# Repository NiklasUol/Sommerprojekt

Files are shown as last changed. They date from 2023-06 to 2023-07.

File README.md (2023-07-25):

# Sommerprojekt
This code is for your university summer project

WHAT THE PROJECT DOES
  Our project is a clock that helps you to wake up. It does that by only being able to turned off by pushing a button that is far away from the clock. 

WHY THE PROJECT IS USEFUL
  With this placement of clock and off-button, we intend to force your users to walk, which makes you more wack and decreases the chance that you lay yourself back into your bed.

HOW USERS CAN GET STARTED WITH THE PROJECT
  Since we tinkered a bit of hardware to getter to build our own clock, it mid be a bit difficult to start right a way. 
  clock and the off-switch consists of a Wemos D1 Mini each, for control and for Wi-Fi capability, an 8-Ohm speaker, button: VS15 and an HT16K33 Display from Adafruit.

WHO MAINTAINS AND CONTRIBUTES TO THE PROJECT & WHERE CAN I GET HELP ?
  This project was created and is maintained by Renke Beckmann, Minh Duc Pham, Niklas Schmidt and Jan von Garrel. 
  If you have any questions on this, feel free to write us a mail at "plantstone98@gmail.com".

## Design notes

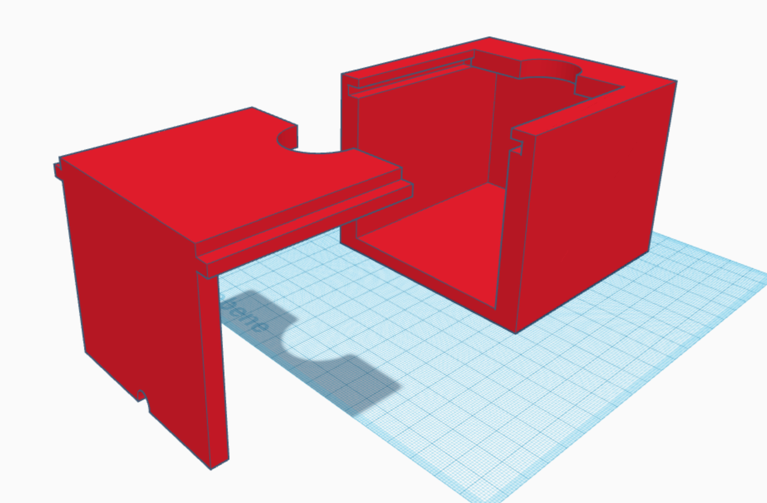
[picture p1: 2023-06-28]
3D Modelle/Knopf/Knopf Gehäuse (offen).png

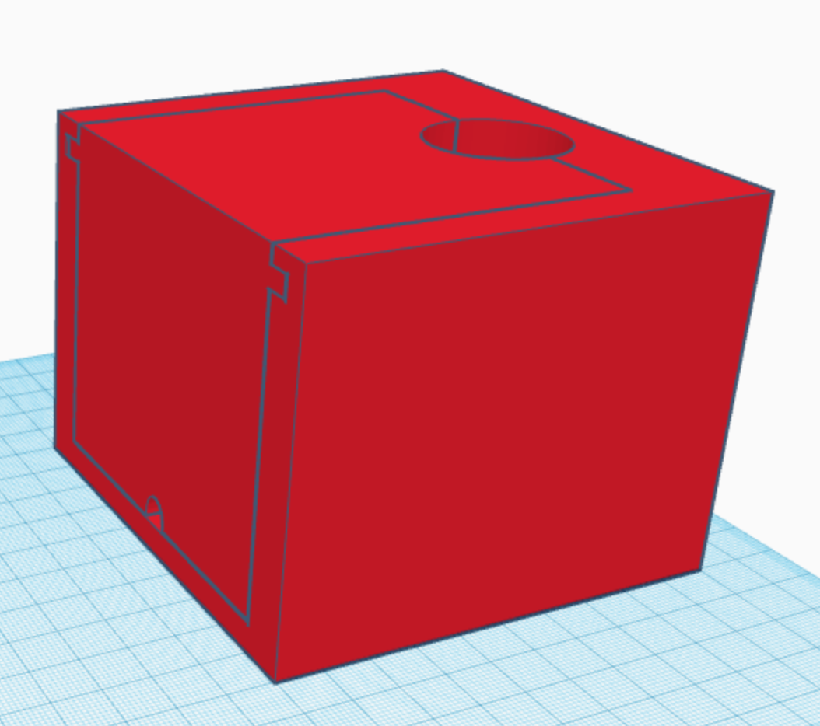
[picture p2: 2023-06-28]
3D Modelle/Knopf/Knopf Gehäuse (geschlossen).png

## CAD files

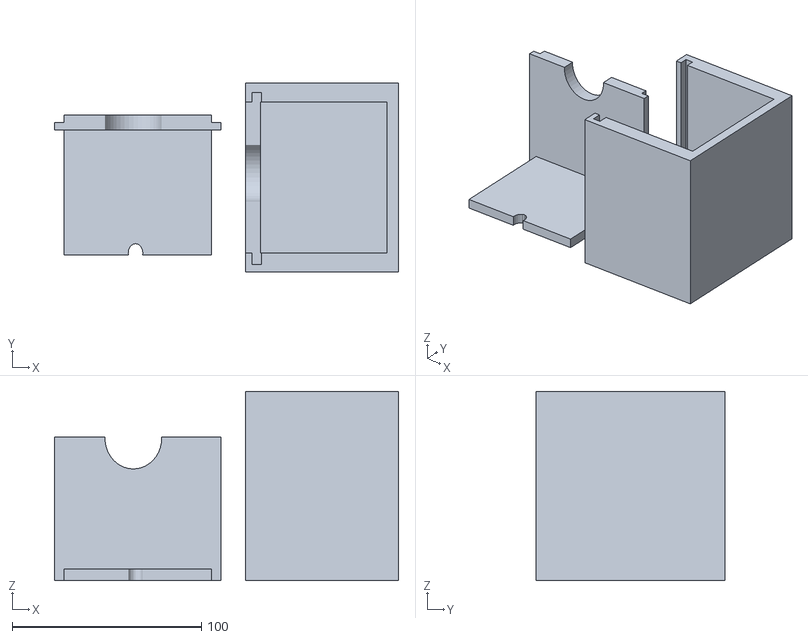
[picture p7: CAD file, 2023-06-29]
3D Modelle/Knopf/Gehäuse Knopf Teil 1 und 2.stl
182.0 x 100.0 x 100.0

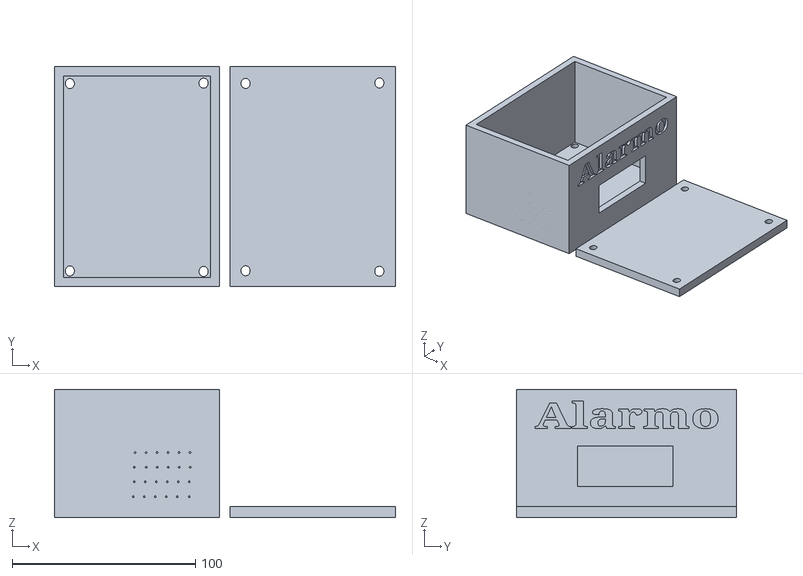
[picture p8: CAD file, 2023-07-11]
3D Modelle/Wecker/Gehäuse Wecker.stl
186.1 x 120.1 x 70.0

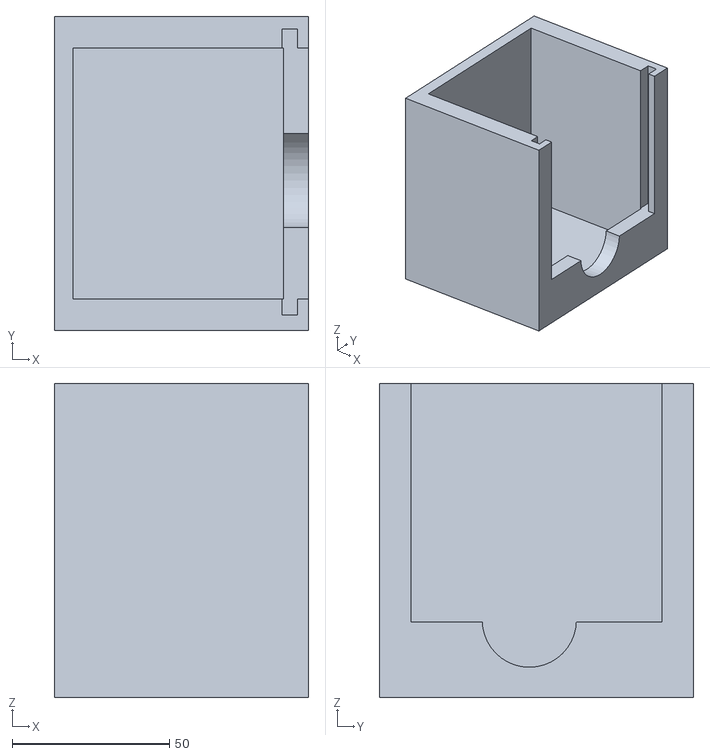
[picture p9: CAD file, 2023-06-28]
3D Modelle/Knopf/Knopf Gehäuse Teil 1.stl
81.0 x 100.0 x 100.0

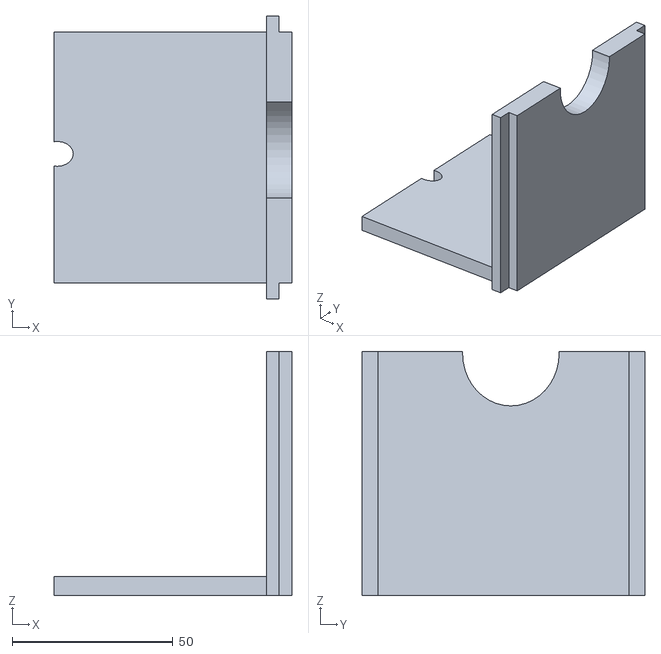
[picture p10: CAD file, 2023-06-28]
3D Modelle/Knopf/Knopf Gehäuse Teil 2.stl
74.0 x 88.0 x 76.0

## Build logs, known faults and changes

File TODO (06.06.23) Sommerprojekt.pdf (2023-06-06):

### TODO

Wecker (Wecker.ino):

- getCurrentTime() : int
- Gibt die aktuelle Uhrzeit zurück. Holt sich diese über WLAN. Methode wird in setup() aufgerufen. Danach wird die Zeit über millis() weiterberechnet.
- updateTime()
- Aktualisiert die Uhrzeit, welche als Attribut gespeichert wird. Dazu kann millis() und die Startuhrzeit, welche in setup() geladen wird, genutzt werden.
- Ruft alarm() auf, wenn die Uhrzeit mit der aktualisierten Weckzeit übereinstimmt.
- alarm()
- Startet den Alarm und setzt ein globales Attribut „alarmAktiv“ auf true. Der Alarm wird so lange abgespielt, bis „alarmAktiv“ false ist. Dazu muss ein Buzzer angesteuert werden.
- onMqttMessage(int messageSize)
- Ist schon vorhanden. Muss so bearbeitet werden, dass auch auf das Topic mit dem Alarm-Stopp-Signal geprüft wird. Wenn ein Signal erhalten wurde, wird das globale Attribut „alarmAktiv“ auf false gesetzt.

Display (Wecker.ino):

- displayTime(int hour, int minute)
- Die aktuelle Zeit wird auf dem Display angezeigt. Dazu wird die Adafruit-Libary genutzt und Inputs und Outputs in setup() gesetzt.

Mobiler-Aus-Knopf (neu zu erstellende Arduino-Projektdatei):

- sendSignal(String signal)
- Es wird ein Signal an den Wecker gesendet. Dazu müssen Broker und Topic mit dem Wecker übereinstimmen.
- Das Signal wird gesendet, wenn der Knopf gedrückt wurde. Diese Bedingung wird in der loop() geprüft. Außerdem muss der digitale Pin des Knopfes definiert- und als Input in setup() gesetzt werden.

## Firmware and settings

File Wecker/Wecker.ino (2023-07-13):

#include <WiFiManager.h>
#include <ArduinoMqttClient.h>

#include <WiFiUdp.h>
#include <NTPClient.h>

//Display
#include <Wire.h>
#include <Adafruit_GFX.h>
#include "Adafruit_LEDBackpack.h"

WiFiManager wifiManager;
WiFiClient client;

//Fuer Zeitabruf
WiFiUDP ntpUDP;
NTPClient timeClient(ntpUDP);

//Mqtt Settings
MqttClient mqttClient(client);
const char broker[] = "broker.hivemq.com";
//const char broker[] = "public.mqtthq.com";

int port = 1883;
const char topicWeckzeit[] = "wecker/weckzeit";
const char topicStopAlarm[] = "wecker/stopAlarm";
const char topicSettings[] = "wecker/settings";

//Wecker-Attribute
int weckminute = 0;
int weckstunde = 0;
bool alarm = false;

bool dimDisplay = false;
bool displayIsDimmed = false;
int dimTime = 22; //22Uhr
int helligkeit = 15;

//Pins (GPIO Nummern entsprechen nicht Anschluessen)
const int buzzer = 14; //D5
const int CLK = D1; //Set the CLK pin connection to the display
const int DIO = D2; //Set the DIO pin connection to the display

Adafruit_7segment display = Adafruit_7segment();

void updateTimeClient();

void setup() {
  Serial.begin(115200);
  display.begin(0x70);
  display.print("LOAd");
  display.blinkRate(3);
  display.setBrightness(helligkeit); //set the diplay to maximum brightness
  display.writeDisplay();
  wifiManager.autoConnect("Wecker");

  mqttSetup();
  mqttSubscribe(topicWeckzeit);
  mqttSubscribe(topicStopAlarm);
  mqttSubscribe(topicSettings);

  timeClient.begin();
  timeClient.setTimeOffset(7200);
  timeClient.setUpdateInterval(86400000);  //Zeit wird alle 24h neu geladen
  updateTimeClient();

  pinMode(buzzer, OUTPUT);
  digitalWrite(buzzer,LOW);

  tone(buzzer, 700, 500);

  display.blinkRate(0);
  display.writeDisplay();
}



void loop() {
  mqttClient.poll();   //Haelt die MQTT Verbindung aufrecht
  updateTimeClient();  //Laedt die Zeit regelmaeßig vom Server
  startAlarm();        //Startet Alarm, wenn die Weckzeit stimmt
  setDisplay(timeClient.getHours(), timeClient.getMinutes()); //Zeitanzeige
 // mqttReconnector();  //Stellt Verbindung wieder her, wenn der Wecker vom Broker getrennt wurde
}



void mqttSetup() {
  Serial.print("Versuche mit folgendem MQTT-Broker zu verbinden: ");
  Serial.println(broker);

  while (!mqttClient.connect(broker, port)) {
    Serial.print("MQTT Verbindung fehlgeschlagen! Error: ");
    Serial.println(mqttClient.connectError());
    tone(buzzer, 100, 500);
    display.print("NOCO");
    display.writeDisplay();
    delay(2000);
  }

  Serial.println("Erfolgreich verbunden!");
  Serial.println();

  mqttClient.onMessage(onMqttMessage);
}

void mqttReconnector(){
  if(!mqttClient.connected()){
    Serial.println("MQTT Verbindung fehlgeschlagen! Versuche Verbindung wiederherzustellen...");
    if(mqttClient.connect(broker, port)){
      Serial.println("MQTT Verbindung wiederhergestellt");
      mqttClient.onMessage(onMqttMessage);
    }
    else{
      Serial.print("Konnte MQTT Verbindung nicht wiederherstellen. Error: ");
      Serial.println(mqttClient.connectError());
      delay(2000);
    }
  }
}

void mqttSubscribe(const char topic[]) {
  mqttClient.subscribe(topic);
  Serial.print("Mit folgendem Mqtt-Topic verbunden: ");
  Serial.println(topic);
}

//Ausgabe der empfangenden Nachricht und Speicherung der Weckzeit
void onMqttMessage(int messageSize) {
  Serial.print("Uhrzeit: ");
  Serial.println(timeClient.getFormattedTime());
  Serial.println("Nachricht mit folgendem Topic erhalten: '");
  String receivedTopic = mqttClient.messageTopic();
  Serial.print(receivedTopic);
  Serial.print("', laenge ");
  Serial.print(messageSize);
  Serial.println(" bytes:");

  // Nachricht lesen und ausgeben
  String nachricht;
  while (mqttClient.available()) {
    nachricht = nachricht + (char)mqttClient.read();
  }
  Serial.println(nachricht);
  Serial.println();

  if (receivedTopic.equals(topicWeckzeit)) {
    Serial.println("Weckzeit " + nachricht + " gespeichert!");
    int deviderIndex = nachricht.indexOf(':');
    weckstunde = nachricht.substring(0, deviderIndex).toInt();
    weckminute = nachricht.substring(deviderIndex + 1).toInt();

    //Sendet Empfangsbestaetigung an Smartphone zurueck
    const char sendTopic[] = "wecker/response";
    sendMqttMessage(sendTopic, "Daten erhalten!");
    
    //Signalton zur Bestätigung
    for(int i = 0; i < 30; i++){
      tone(buzzer, 300 + (20 * i), 100);
    }
    
    //Wecker zeigt empfangende Zeit an
    for(int i = 0; i < 5; i++){
      setDisplay(weckstunde, weckminute);
      delay(1000);
      display.clear();
      display.writeDisplay();
      delay(1000);
    }
  }

  if (receivedTopic.equals(topicStopAlarm)) {
    alarm = false;
    Serial.println("Alarm gestopp!");
  }

  if(receivedTopic.equals(topicSettings)){
    int receivedHelligkeit = nachricht.substring(0).toInt();
    if(receivedHelligkeit == 0){
      helligkeit = 0;
    }
    else{
      helligkeit = receivedHelligkeit * 2 + 1;
    }
    display.setBrightness(helligkeit);
    display.writeDisplay();
    sendMqttMessage("wecker/response", "Settings erhalten");
    tone(buzzer, 700, 500);

    if(nachricht.length() > 1){
      dimTime = nachricht.substring(2, nachricht.length()).toInt();
      dimDisplay = true;
    }
    else {
      dimDisplay = false;
      displayIsDimmed = false;
    }
  }
}

void sendMqttMessage(const char sendTopic[], String message) {
  mqttClient.beginMessage(sendTopic);
  mqttClient.print(message);
  mqttClient.endMessage();
}

//Laedt die Zeit von einem Zeitserver herunter
//Muss nicht bei jedem Zeitabruf verwendet werden, da die Zeit auch so weiterlaeuft
//(Stattdessen z.B. timeClient.getHours())
void updateTimeClient() {
  if (timeClient.update()) {
    Serial.println("Zeit geladen!");
    Serial.print("Stunde: ");
    Serial.print(timeClient.getHours());
    Serial.print(", Minute: ");
    Serial.println(timeClient.getMinutes());
    Serial.println();
  }
}

bool dimDone = false;

void setDisplay(int hours, int minutes) {
  //TODO: Display Programmierung hinzufügen
  int time = (hours * 100) + minutes;
  if(!displayIsDimmed){
    display.print(time);
    display.drawColon(true);
    if(!dimDone && dimDisplay && timeClient.getHours() == dimTime){
    display.setBrightness(0);
    display.clear();
    displayIsDimmed = true;
    dimDone = true;
    }
    display.writeDisplay();
  }

  if(dimDone && dimTime != hours){
    dimDone = false;
  }
}


bool alarmDone = false;

void startAlarm() {
  if (timeClient.getHours() == weckstunde && timeClient.getMinutes() == weckminute && !alarmDone) {
    alarm = true;
    Serial.println("Alarm gestartet...");
    display.setBrightness(helligkeit);
    display.writeDisplay();
    displayIsDimmed = false;
    while (alarm) {
      Serial.println("Alarm");
      tone(buzzer,500);
      delay(400);
      display.clear();
      display.writeDisplay();
      noTone(buzzer);
      delay(400);

      setDisplay(timeClient.getHours(), timeClient.getMinutes());
      mqttClient.poll();
    }
    alarmDone = true;
  }
  
  //Verhindert erneute Auslösung des Alarms
  else if (!(timeClient.getHours() == weckstunde && timeClient.getMinutes() == weckminute) && alarmDone) {
    alarmDone = false;
  }
}

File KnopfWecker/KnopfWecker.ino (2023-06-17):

#include <WiFiManager.h>
#include <ArduinoMqttClient.h>

WiFiManager wifiManager;
WiFiClient client;


//MQTT Settings
MqttClient mqttClient(client);
const char broker[] = "broker.hivemq.com";
//const char broker[] = "public.mqtthq.com";
int        port     = 1883;
const char topic[]  = "wecker/stopAlarm";

const int knopf = 14; //D5

void setup() {
  Serial.begin(115200);
  Serial.setTimeout(10);
  wifiManager.autoConnect("Aus-Knopf");
  mqttSetup();

  pinMode(knopf, INPUT);
}

void mqttSetup(){
  Serial.print("Versuche mit folgendem MQTT-Broker zu verbinden: ");
  Serial.println(broker);

  if (!mqttClient.connect(broker, port)) {
    Serial.print("MQTT Verbindung fehlgeschlagen! Error: ");
    Serial.println(mqttClient.connectError());

    while (1);
  }

  Serial.println("Erfolgreich verbunden!");
  Serial.println();

}
void loop() {
  mqttClient.poll();
  
  //if(Serial.available() > 0 ){   //Zum Testen in der Konsole
  if(digitalRead(knopf) == HIGH){
    sendSignal();
    Serial.print("Signal gesendet.");
    Serial.print(Serial.readString());
    delay(1500);
  }
}

void sendSignal(){
  mqttClient.beginMessage(topic);
  mqttClient.print("Stop Alarm!");
  mqttClient.endMessage();
  }

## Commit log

2023-06-01 Create Wecker.ino
    Der Wecker kann nun die Weckzeit über MQTT empfangen. Aktuell wird noch HiveMQ als Broker genutzt.
    [Wecker.ino]
2023-06-01 Android Wecker App
    Es wurde eine App programmiert, welche die Weckzeit über MQTT an den Wecker schicken kann.
2023-06-02 Apk zur Installation der App hinzugefügt
2023-06-04 Aktuelle Uhrzeit kann jetzt abgerufen werden.
    Um die Uhrzeit abzurufen, timeClient.getHours() bzw. timeClient.getMinutes() aufrufen.
2023-06-04 Create NTPClient-master.zip
    Die Library ist wichtig, um die Zeit von einem Server abrufen zu können.
2023-06-04 Weckzeit wird als Minute und Stunde abgespeichert
    Die MQTT-Message mit der Weckzeit (String) wird direkt in "weckminute" und "weckstunde" vom Typ int gespeichert.
2023-06-04 timeClient synchronisiert die Zeit regelmäßig mit Server
2023-06-08 Der Alarm wird aktiviert
2023-06-09 Rückmeldung beim Senden der Weckzeit verbessert
2023-06-14 Piezo und Button Problem gelöst
    [Wecker.ino]
2023-06-15 Knöpfe und Buzzer implementiert, SSID geändert.
    [KnopfWecker.ino, Wecker.ino]
2023-06-17 Settings-Page in der App hinzugefügt
    Broker und Port lassen sich konfigurieren. Der Start der App ist nun deutlich schneller, wenn der Broker nicht erreichbar ist.
2023-06-28 3D-Modell für Knopf-Gehäuse erstellt
    [Knopf Gehäuse Teil 1.stl, Knopf Gehäuse Teil 2.stl]
2023-06-29 Create Gehäuse Knopf Teil 1 und 2.stl
    [Gehäuse Knopf Teil 1 und 2.stl]
2023-07-02 Deaktivierung des Displays ab bestimmmten Uhrzeiten möglich
2023-07-09 MQTT-Verbindung verbessert
    Wecker kann die Verbindung zum MQTT-Broker wieder selbstständig herstellen.
    [Wecker.ino]
2023-07-10 Modelle einsortiert
    [Gehäuse Knopf Teil 1 und 2.stl, Knopf Gehäuse Teil 1.stl, Knopf Gehäuse Teil 2.stl]
2023-07-11 3D Modelle Gehäuse von Wecker hinzugefügt
    [Gehäuse Wecker.stl]
2023-07-25 Create README.md
    Ich (Jan) habe die wichtigsten Punkte aufgeführt.
